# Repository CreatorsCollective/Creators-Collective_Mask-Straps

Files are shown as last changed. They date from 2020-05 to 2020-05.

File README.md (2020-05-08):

# CREATORS COLLECTIVE - Mask-Strap / Masken-Bügel
Der von **CREATORS** COLLECTIVE entwickelte Bügel entlastet die Ohren beim Tragen von Atemschutzmasken. Das Design ist dabei extra minimalistisch, um ein schnelles Drucken zu ermöglichen und trotzdem ein angenehmes Tragen zu gewährleisten.



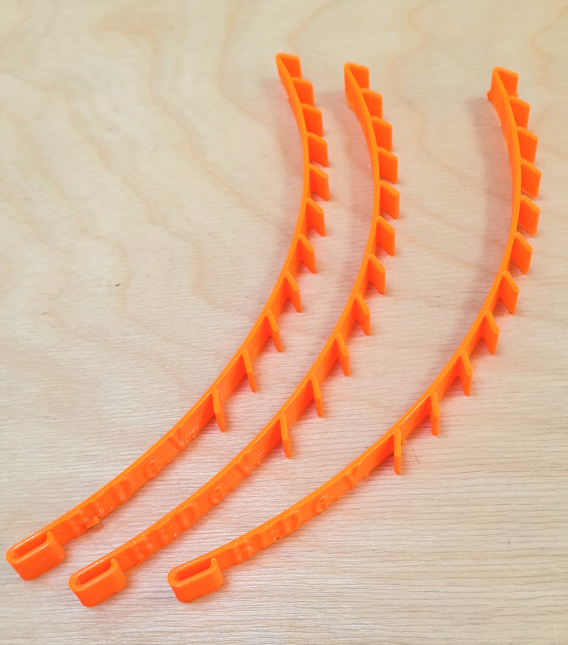
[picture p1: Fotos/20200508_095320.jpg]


Ziel war es möglichst schnell und mit möglichst wenig Materialeinsatz die Funktion zu gewährleisten. Der Bügel ist in vielen Varianten getestet und wir haben uns schließlich für das Design entschieden. Es können beispielsweise auf einem Prusa MK3S mindestens 40 Stück gleichzeitig und in kürzester Zeit gedruckt werden.

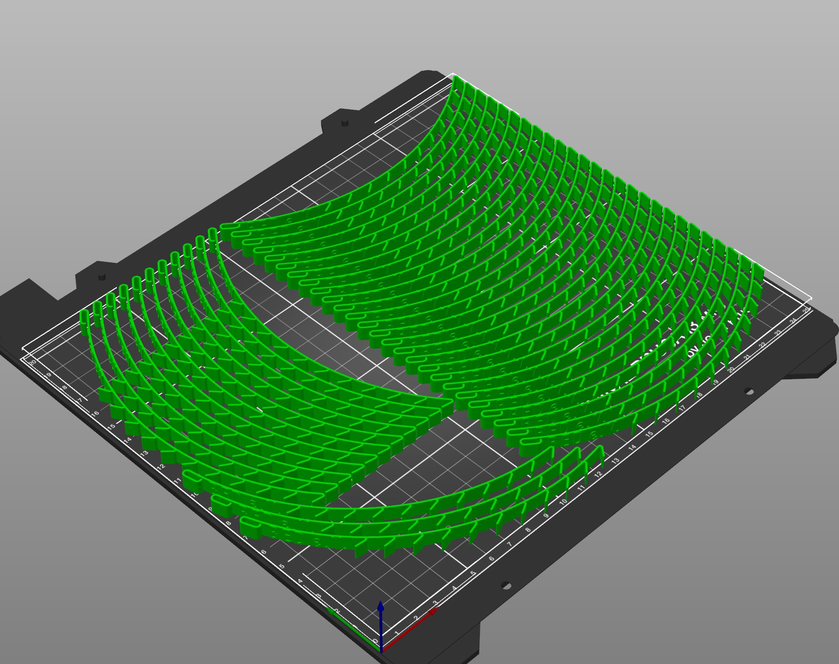
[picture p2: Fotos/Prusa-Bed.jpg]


## Funktion
Derr Bügel kann einseitig in eine handelsübliche (oder selbstgenähte) Atemschutzmaske eingehakt werden. Durch den Haken wird der Bügel festgehalten und fällt nicht einfach so aus dem Gummiband heraus.

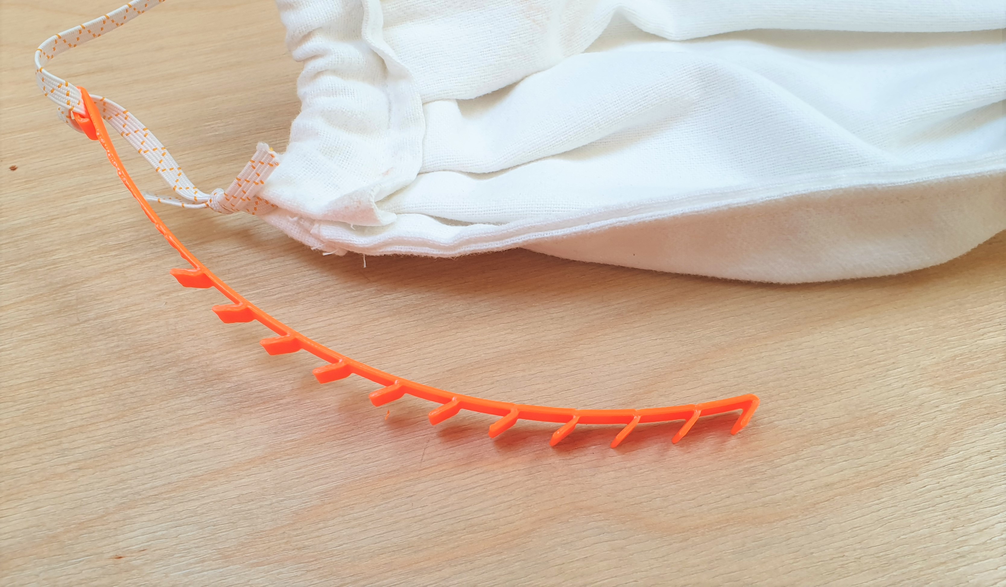
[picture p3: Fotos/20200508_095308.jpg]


Dann wird die Maske angezogen und das zweite Gummiband einfach in eine der Haken am Bügel eingehängt. Die Größe der Maske ist dabei variabel, da mehrere Haken vorhanden sind. 

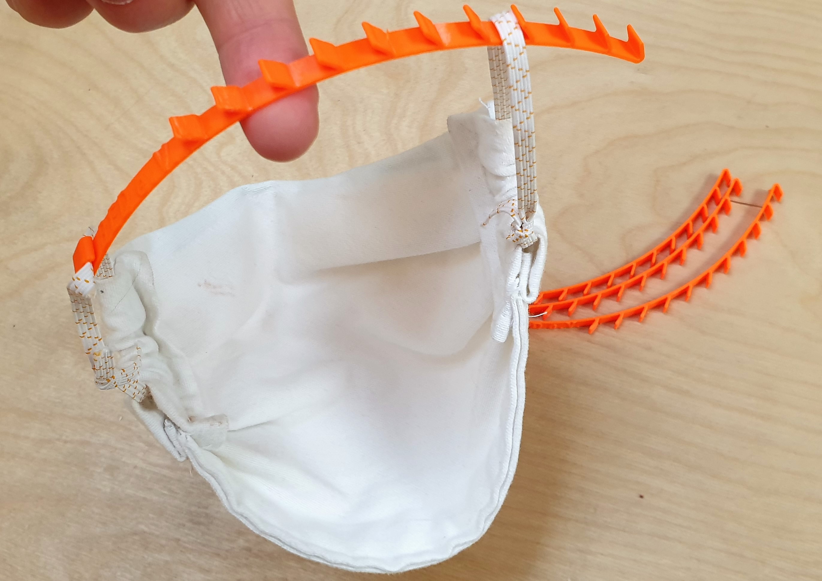
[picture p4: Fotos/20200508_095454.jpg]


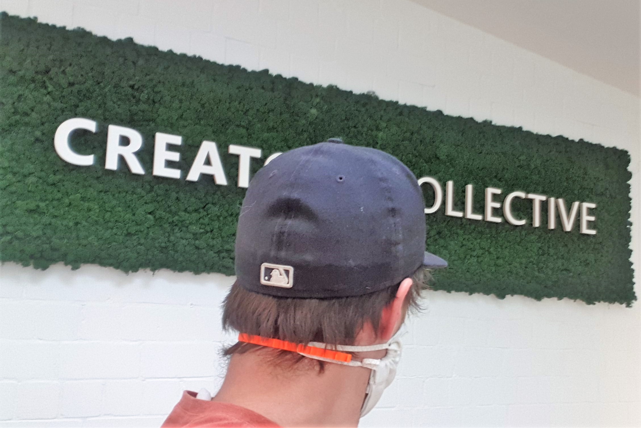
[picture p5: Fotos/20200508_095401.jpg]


## Die Dateien
Alle Dateien beinhalten den **gleichen Bügel in unterschiedlichen Wandstärken und zwei Längen**. Bei uns in allen Tests war die Wandstärke 0,8 mm optimal. Dabei ist der Bügel ausreichend stabil und trotzdem optimal weich und flexibel, um einen hohen Tragekomfort zu bieten.

Andere Wandstärken sind vor allem dann sinnvoll, wenn andere Düsendurchmesser oder andere Konturbreiten verwendet werden als 0,4mm. Der Bügel ist so konzipiert, dass er optimalerweise **mit nur einer geschlossenen Aussenkontur** (komplette Umrundung ohne Unterbrechung) gedruckt werden kann. Der Bügel kann demnach auch im Vasenmodus gedruckt werden.

Die XL-Variante ist deutlich länger und kann nach Belieben mit einer handelsüblichen Schere abgeschnitten werden. So können auch andere Längen erzielt werden.

## Druckparameter
Wie bereits oben erwähnt, ist der Bügel so entwickelt, dass er mit eine komplett umlaufenden, geschlossenen Aussenkontur ohne Infill gedruckt werden kann. Wichtig ist beim Slicer den "Dünne Wand"-Modus zu deaktivieren, da sonst versucht wird den Bügel mit nur einer (offenen, nicht umlaufenden) Kontur zu drucken. Das Slicing-Ergebnis sollte ungefähr so aussehen:

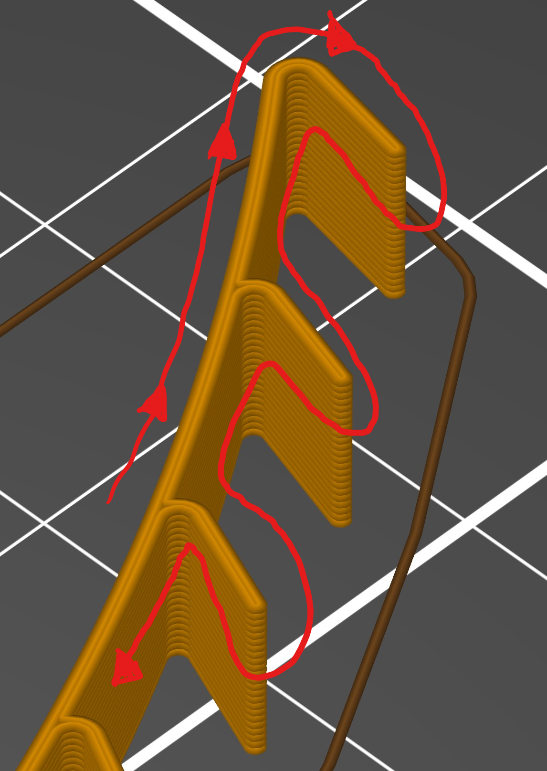
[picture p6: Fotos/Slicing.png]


### Zusammenfassende Druckparameter:
- "Dünne Wand"-Modus deaktivieren
- Schichthöhe: 0,3mm
- Infill: 0%
- Stapeln funktioniert nicht ohne weiteres
- Material: PETG (PLA möglich)
- Wandstärke: bevorzugt 0,8mm (Bei PLA mindestens 1mm Wandstärke)

## Sonstige Hinweise
Wir können keine Gewährleistung für die Funktion geben. Das Nutzen geschieht auf eigene Gefahr und nach eigenem Ermessen.

Das 3D-Modell kann nach Belieben verändern und genutzt werden, **nicht aber für kommerzielle Zwecke!** Der Entwurf steht unter Lizenz: [Creative Commons (4.0 International License)](https://creativecommons.org/licenses/by-nc/4.0/)

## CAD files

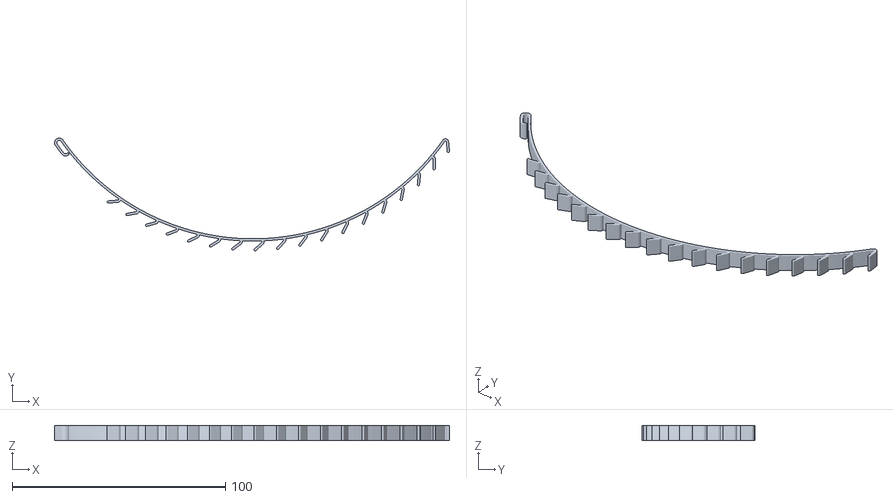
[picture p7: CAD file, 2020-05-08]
CC_Mask-Strap_11_XL.stl
185.3 x 52.9 x 7.00

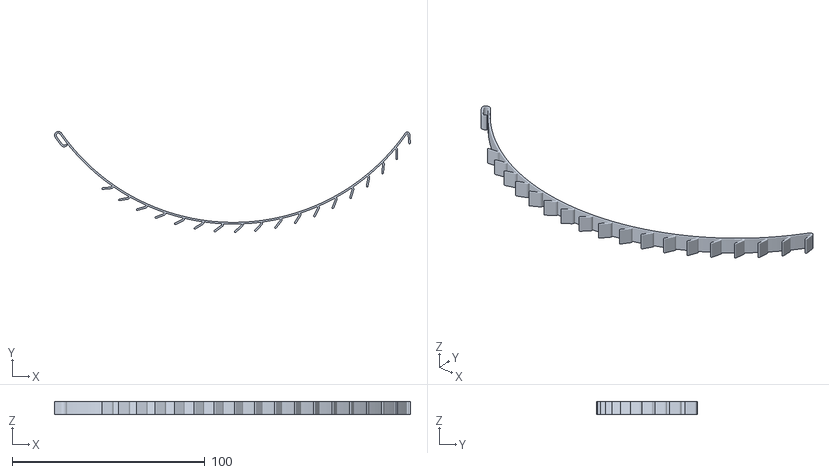
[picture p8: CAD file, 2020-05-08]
CC_Mask-Strap_09_XL.stl
184.9 x 52.5 x 7.00

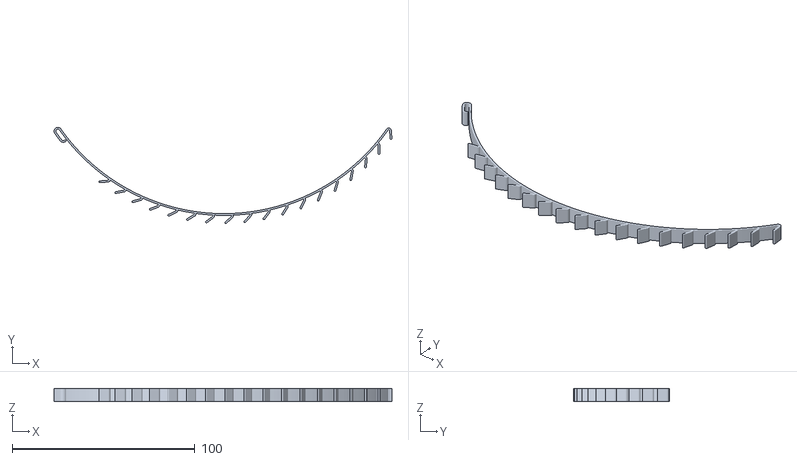
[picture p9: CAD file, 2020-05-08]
CC_Mask-Strap_10_XL.stl
185.1 x 52.7 x 7.00

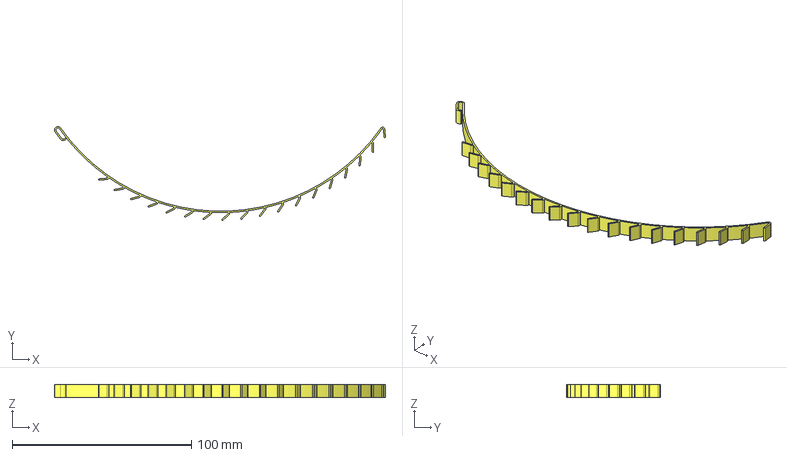
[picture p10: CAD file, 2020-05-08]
CC_Mask-Strap_XL.stp
184.7 x 52.4 x 7.00 mm

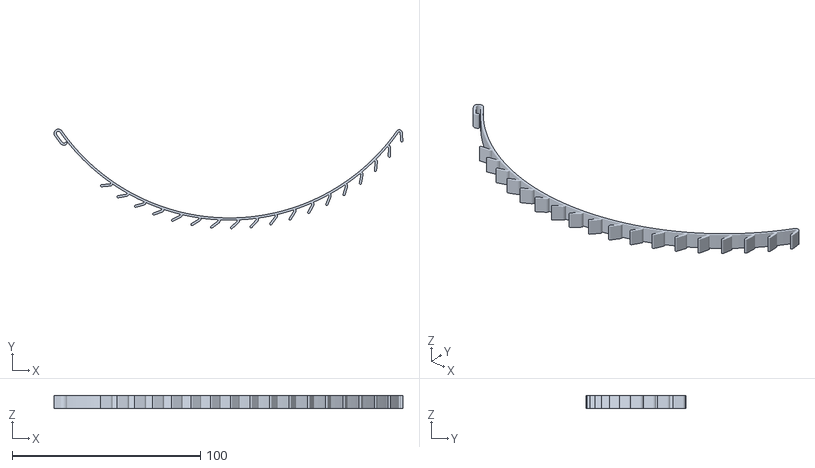
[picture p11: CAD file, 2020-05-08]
CC_Mask-Strap_12_XL.stl
185.5 x 53.1 x 7.00

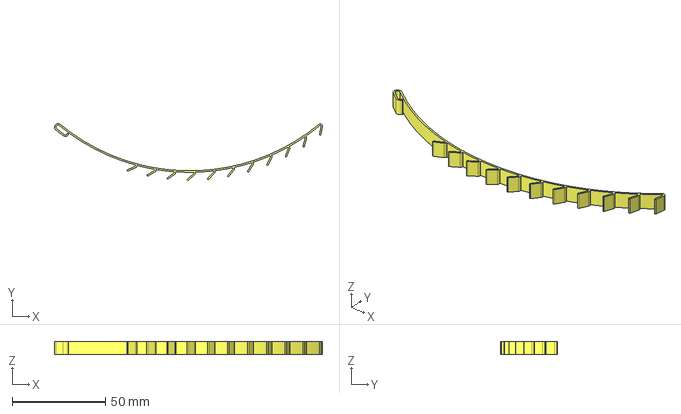
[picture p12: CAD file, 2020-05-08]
CC_Mask-Strap08.stp
144.1 x 30.5 x 7.00 mm

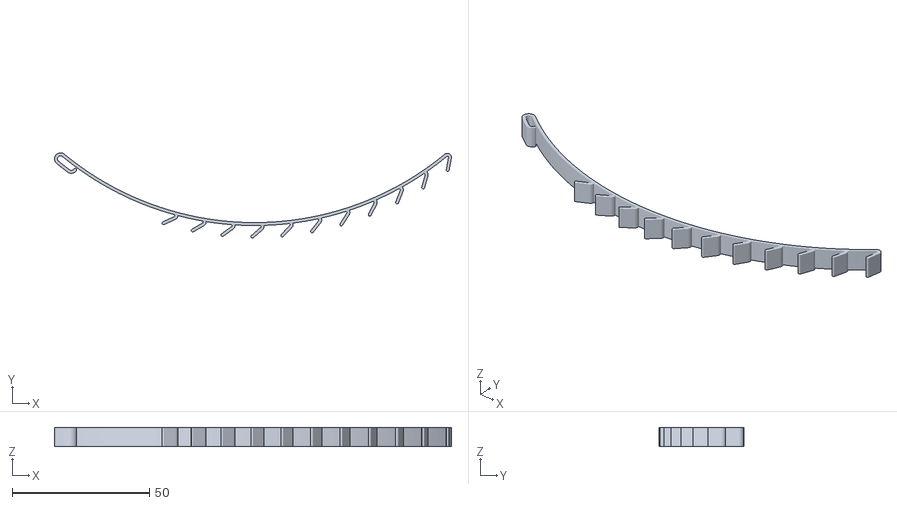
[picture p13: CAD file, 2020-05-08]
CC_Mask-Strap_11.stl
144.7 x 31.1 x 7.00

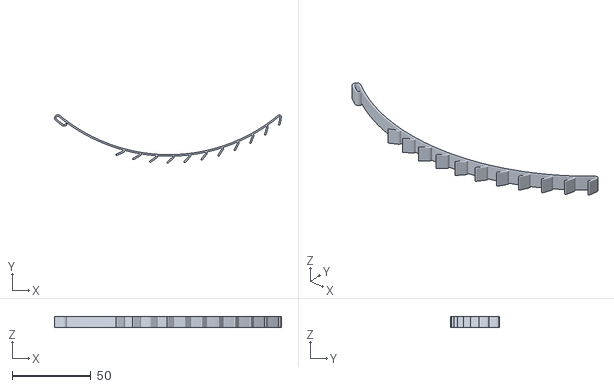
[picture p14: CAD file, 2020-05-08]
CC_Mask-Strap_10.stl
144.5 x 30.9 x 7.00

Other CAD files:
CC_Mask-Strap_08_XL.stl
CC_Mask-Strap.stp
CC_Mask-Strap_09.stl
CC_Mask-Strap_12.stl
CC_Mask-Strap_08.stl
